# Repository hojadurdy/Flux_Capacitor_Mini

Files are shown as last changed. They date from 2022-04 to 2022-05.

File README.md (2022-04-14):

# Flux Capacitor Mini

LED Numbers

### WHAT IS IT?
A miniature version of Flux Capacitor from the movie trilogy Back to the Future. Measuring at only 48mm x 38mm (1.89in x 1.5in), it can be easily pocketable . It is constructed with high quality 3D printed frame, sandwiched between stacked Gold Plated PCBs. Featuring 24 LEDs, diffused through bare FR4 material, that animate to create the “fluxxing” effect. It’s 100% decorative, it doesn’t actually let you travel through time. But let's not lose hope. Maybe in the future.

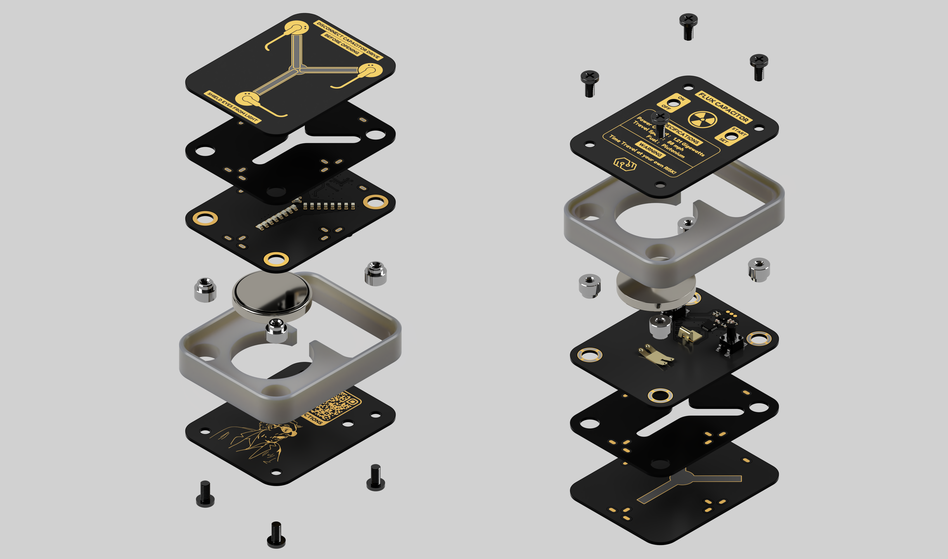
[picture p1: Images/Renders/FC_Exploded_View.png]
LED Numbers


This mini Flux Capacitor is controlled by a Microchip ATtiny816 microcontroller. By using PWM (Pulse Width Modulation) pins for 8 channels of 3 paralleled LEDs, different animation patterns are generated for the fluxxxing effect. In settings mode, users are able change the animation type, speed, and LED brightness. There are 8 animations, 4 animation speeds, 4 LED brightness levels (100%, 75%, 50% and 25%).

### DEVICE SETTINGS
To set your desired animation, speed and LED brightness, you have to start flux condenser in Settings Mode. In order to do that, first you have to turn off your Flux Capacitor (if it's on) by holding "On/Off" button for 3 seconds **(you always have to hold the "On/Off" button for 3 seconds to turn it on or off)**. While holding the “Start/Set” button on the back turn the Flux Capacitor on by holing "On/Off" button for 3 seconds. You can release both buttons when you see all the LEDs start to light up one by one. Now you're in Settings Mode. Some of the LEDs should be on at full brightness and some very dimly lit (so you can see them through FR4 diffuser) according to the configuration it was set. LEDs on each row of all columns, starting from outer to inner are paralleled. LEDs are numbered as shown in the photo below to represent a setting for each LED.

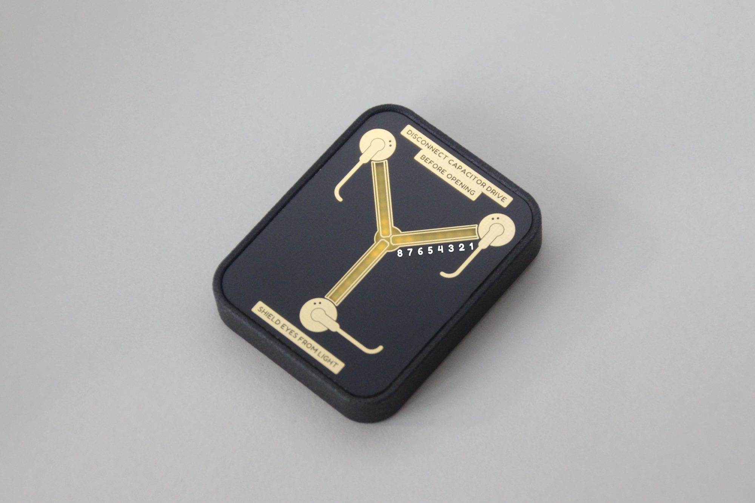
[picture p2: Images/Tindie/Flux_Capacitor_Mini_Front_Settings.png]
Settings


The LEDs display the settings in binary. If it's fully lit then it is shows "on state or in binary 1" and if it's very dimly lit then it is shows "off state or 0 in binary". 
Now the combinations of the LEDs numbered 3, 2, and 1 sets your main animation. If you set those LEDs to different on/off states, you get 8 total combinations and on each set combination LEDs animate in different patterns.
LED number 4 displays setting for flashing animation which animates when you press "Start/Set" button in normal operation. With one LED you get only 2 combination either on or off.
LEDs numbered 5 and 6 displays the setting for animation speed. 2 LEDs make 4 total combinations. For each combination LEDs animate very slow, slow, fast or very fast.
LEDs numbered 7 and 8 displays the setting for LED brightness. For each of the 4 combinations LEDs light up at 25%, 50%, 75% or 100%.
All of the combinations, and setting examğles are shown in the tables below.

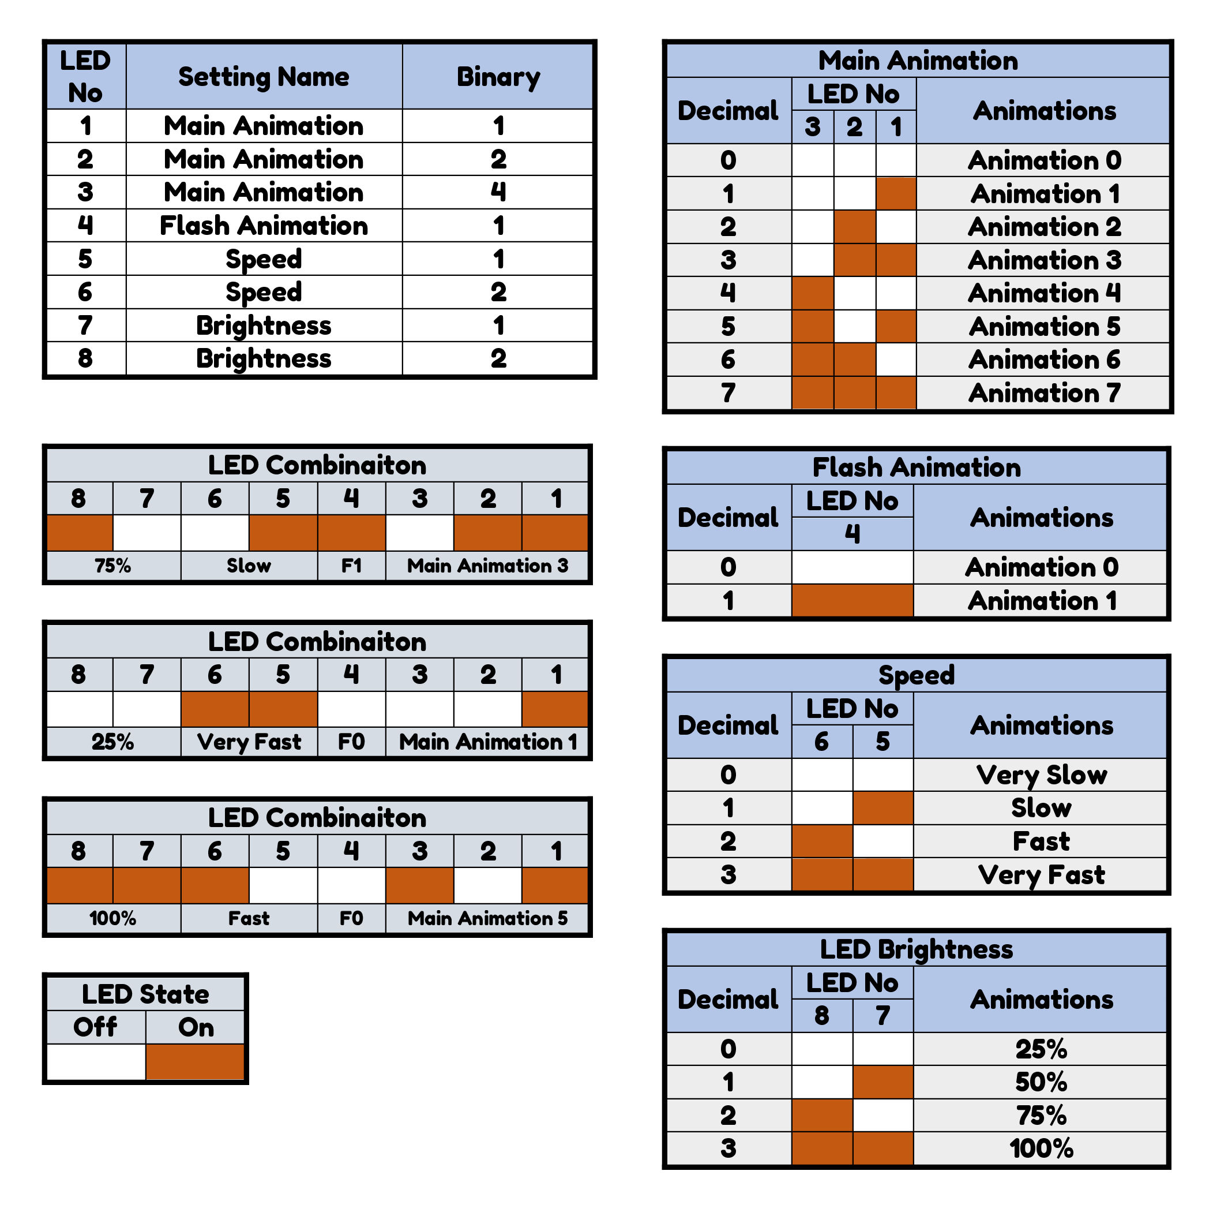
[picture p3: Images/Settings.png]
Settings


You don't have to remember these. There is a QR code on the interior side of back cover PCB. Scan it and it will take you to this page.
To change the LED state, while in Settings Mode, hold the "Start/Set" button. All the LEDs should be turned on very dimly and second after that, starting from LED1 each individual LED gets fully lit. Hold the "Start/Set" button until the fully lit LED reaches the one you want to change. When you change the LED state, if the LED is already set on, it turns off (or dimly lit). If it's at off state (or dimly lit) then it turns on at full brightness. 
If all of this feels complicated to you then I can program the Flux Capacitor with older much simpler version of the firmware by your request. But the older firmware has less functionality. Check it **[HERE](https://www.youtube.com/watch?v=2X2gqoI-mSA)**

You don't have to remember these. There is a QR code on the interior side of back cover PCB. Scan it and it will take you to this page.

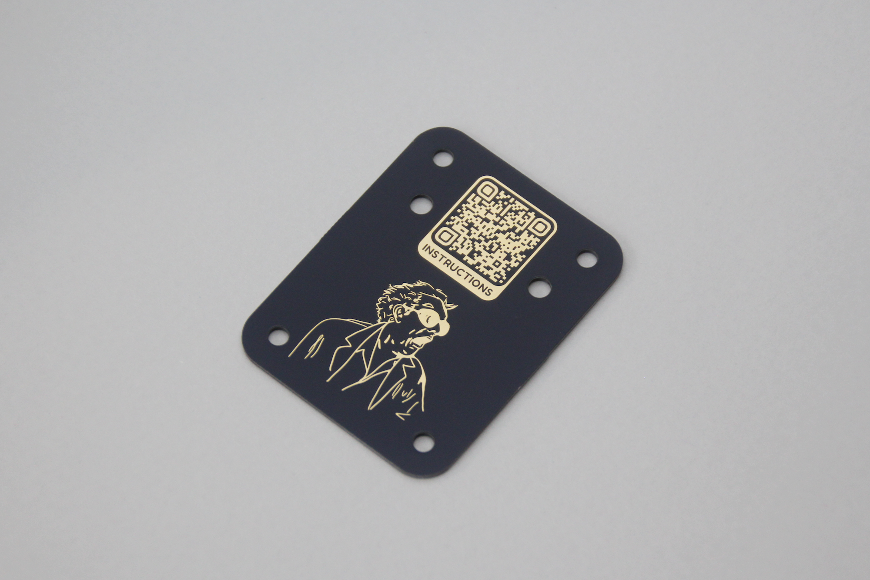
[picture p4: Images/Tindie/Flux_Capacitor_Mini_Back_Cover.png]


Below, all of the LED animations and their LED setting combinations are shown. Also animation patterns might seem different when you run them at different speeds.

https://user-images.githubusercontent.com/43648325/163351795-e4758084-3ac4-411a-833b-632b1832e1c3.mov

https://user-images.githubusercontent.com/43648325/163351857-c6b9a43f-3085-4918-af22-fd343d08b809.mov

https://user-images.githubusercontent.com/43648325/163352711-5db71f97-86e2-47c3-9c65-f71232630f72.mov

https://user-images.githubusercontent.com/43648325/163353298-47ecd2d0-05f4-4908-87b2-38960816e004.mov

### POWER REQUIREMENT
Device requires 1.21 Gigawatts ("Jigowatts") of power to operate. That amount of power is no match for an ordinary power supply. Luckily we've developed a miniature nuclear reactor named LIR2032 that needs to be placed inside the device. LIR2032 also encapsulates a small pellet of Plutonium to be used as fuel to generate enough power. This miniature reactor is able to supply all the power required for the Flux Capacitor. Ok, joke aside this entire paragraph is totally not true.

To really power it, you only need a non-rechargeable CR2032 or rechargeable LIR2032 coin cell battery. Power consumption is drastically lowered. At full brightness, it draws 3.7mA and at 25% brightness it draws 1.8mA of current from the battery. 

CR2032 (Non-Rechargeable) with average of 210mAh battery capacity.

- 100% LED Brightness :  57 Hours
- 25%  LED Brightness :  110 Hours

LIR2032 (Rechargeable) with average of 40mAh battery capacity.

- 100% LED Brightness :  11 Hours
- 25%  LED Brightness :  21 Hours

### WHAT MAKES THIS DEVICE SPECIAL?
First of all, the gold plating on the PCB makes it look luxurious. You can wear it around your neck with an ID card strap, hang it on your keychain or... you can place it on your car's dashboard and try and see if the time travel is possible while you're driving at 88mph. Time travel at your own RISK! If you stuck in unknown territories of time, try turning on the SOS mode of the Flux Capacitor (Animation 5 or 101 LED combination). Help may or may not arrive. NO GUARANTEES. 

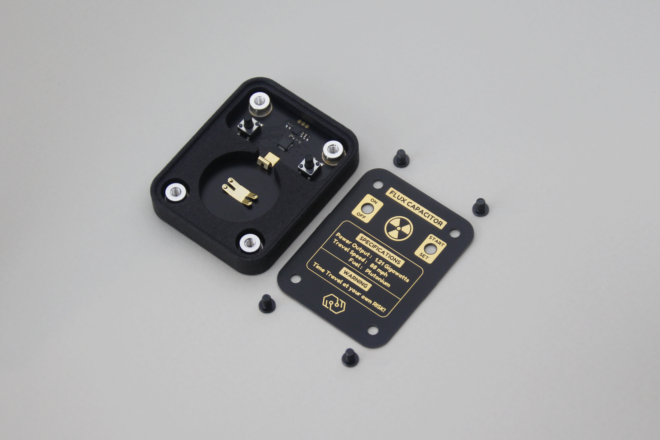
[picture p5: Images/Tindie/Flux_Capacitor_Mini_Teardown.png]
Teardown




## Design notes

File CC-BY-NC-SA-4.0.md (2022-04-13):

# CC-BY-NC-SA-4.0
## Creative Commons Attribution-NonCommercial-ShareAlike 4.0 International

Creative Commons Corporation ("Creative Commons") is not a law firm and
does not provide legal services or legal advice. Distribution of
Creative Commons public licenses does not create a lawyer-client or
other relationship. Creative Commons makes its licenses and related
information available on an "as-is" basis. Creative Commons gives no
warranties regarding its licenses, any material licensed under their
terms and conditions, or any related information. Creative Commons
disclaims all liability for damages resulting from their use to the
fullest extent possible.

Using Creative Commons Public Licenses

Creative Commons public licenses provide a standard set of terms and
conditions that creators and other rights holders may use to share
original works of authorship and other material subject to copyright and
certain other rights specified in the public license below. The
following considerations are for informational purposes only, are not
exhaustive, and do not form part of our licenses.

Considerations for licensors: Our public licenses are intended for use
by those authorized to give the public permission to use material in
ways otherwise restricted by copyright and certain other rights. Our
licenses are irrevocable. Licensors should read and understand the terms
and conditions of the license they choose before applying it. Licensors
should also secure all rights necessary before applying our licenses so
that the public can reuse the material as expected. Licensors should
clearly mark any material not subject to the license. This includes
other CC-licensed material, or material used under an exception or
limitation to copyright. More considerations for licensors :
wiki.creativecommons.org/Considerations\_for\_licensors

Considerations for the public: By using one of our public licenses, a
licensor grants the public permission to use the licensed material under
specified terms and conditions. If the licensor's permission is not
necessary for any reason–for example, because of any applicable
exception or limitation to copyright–then that use is not regulated by
the license. Our licenses grant only permissions under copyright and
certain other rights that a licensor has authority to grant. Use of the
licensed material may still be restricted for other reasons, including
because others have copyright or other rights in the material. A
licensor may make special requests, such as asking that all changes be
marked or described. Although not required by our licenses, you are
encouraged to respect those requests where reasonable. More
considerations for the public :
wiki.creativecommons.org/Considerations\_for\_licensees

Creative Commons Attribution-NonCommercial-ShareAlike 4.0 International
Public License

By exercising the Licensed Rights (defined below), You accept and agree
to be bound by the terms and conditions of this Creative Commons
Attribution-NonCommercial-ShareAlike 4.0 International Public License
("Public License"). To the extent this Public License may be interpreted
as a contract, You are granted the Licensed Rights in consideration of
Your acceptance of these terms and conditions, and the Licensor grants
You such rights in consideration of benefits the Licensor receives from
making the Licensed Material available under these terms and conditions.

Section 1 – Definitions.

-   a. Adapted Material means material subject to Copyright and Similar
    Rights that is derived from or based upon the Licensed Material and
    in which the Licensed Material is translated, altered, arranged,
    transformed, or otherwise modified in a manner requiring permission
    under the Copyright and Similar Rights held by the Licensor. For
    purposes of this Public License, where the Licensed Material is a
    musical work, performance, or sound recording, Adapted Material is
    always produced where the Licensed Material is synched in timed
    relation with a moving image.
-   b. Adapter's License means the license You apply to Your Copyright
    and Similar Rights in Your contributions to Adapted Material in
    accordance with the terms and conditions of this Public License.
-   c. BY-NC-SA Compatible License means a license listed at
    creativecommons.org/compatiblelicenses, approved by Creative Commons
    as essentially the equivalent of this Public License.
-   d. Copyright and Similar Rights means copyright and/or similar
    rights closely related to copyright including, without limitation,
    performance, broadcast, sound recording, and Sui Generis Database
    Rights, without regard to how the rights are labeled or categorized.
    For purposes of this Public License, the rights specified in Section
    2(b)(1)-(2) are not Copyright and Similar Rights.
-   e. Effective Technological Measures means those measures that, in
    the absence of proper authority, may not be circumvented under laws
    fulfilling obligations under Article 11 of the WIPO Copyright Treaty
    adopted on December 20, 1996, and/or similar international
    agreements.
-   f. Exceptions and Limitations means fair use, fair dealing, and/or
    any other exception or limitation to Copyright and Similar Rights
    that applies to Your use of the Licensed Material.
-   g. License Elements means the license attributes listed in the name
    of a Creative Commons Public License. The License Elements of this
    Public License are Attribution, NonCommercial, and ShareAlike.
-   h. Licensed Material means the artistic or literary work, database,
    or other material to which the Licensor applied this Public License.
-   i. Licensed Rights means the rights granted to You subject to the
    terms and conditions of this Public License, which are limited to
    all Copyright and Similar Rights that apply to Your use of the
    Licensed Material and that the Licensor has authority to license.
-   j. Licensor means the individual(s) or entity(ies) granting rights
    under this Public License.
-   k. NonCommercial means not primarily intended for or directed
    towards commercial advantage or monetary compensation. For purposes
    of this Public License, the exchange of the Licensed Material for
    other material subject to Copyright and Similar Rights by digital
    file-sharing or similar means is NonCommercial provided there is no
    payment of monetary compensation in connection with the exchange.
-   l. Share means to provide material to the public by any means or
    process that requires permission under the Licensed Rights, such as
    reproduction, public display, public performance, distribution,
    dissemination, communication, or importation, and to make material
    available to the public including in ways that members of the public
    may access the material from a place and at a time individually
    chosen by them.
-   m. Sui Generis Database Rights means rights other than copyright
    resulting from Directive 96/9/EC of the European Parliament and of
    the Council of 11 March 1996 on the legal protection of databases,
    as amended and/or succeeded, as well as other essentially equivalent
    rights anywhere in the world.
-   n. You means the individual or entity exercising the Licensed Rights
    under this Public License. Your has a corresponding meaning.

Section 2 – Scope.

-   a. License grant.
    -   1. Subject to the terms and conditions of this Public License,
        the Licensor hereby grants You a worldwide, royalty-free,
        non-sublicensable, non-exclusive, irrevocable license to
        exercise the Licensed Rights in the Licensed Material to:
        -   A. reproduce and Share the Licensed Material, in whole or in
            part, for NonCommercial purposes only; and
        -   B. produce, reproduce, and Share Adapted Material for
            NonCommercial purposes only.
    -   2. Exceptions and Limitations. For the avoidance of doubt, where
        Exceptions and Limitations apply to Your use, this Public
        License does not apply, and You do not need to comply with its
        terms and conditions.
    -   3. Term. The term of this Public License is specified in Section
        6(a).
    -   4. Media and formats; technical modifications allowed. The
        Licensor authorizes You to exercise the Licensed Rights in all
        media and formats whether now known or hereafter created, and to
        make technical modifications necessary to do so. The Licensor
        waives and/or agrees not to assert any right or authority to
        forbid You from making technical modifications necessary to
        exercise the Licensed Rights, including technical modifications
        necessary to circumvent Effective Technological Measures. For
        purposes of this Public License, simply making modifications
        authorized by this Section 2(a)(4) never produces Adapted
        Material.
    -   5. Downstream recipients.
        -   A. Offer from the Licensor – Licensed Material. Every
            recipient of the Licensed Material automatically receives an
            offer from the Licensor to exercise the Licensed Rights
            under the terms and conditions of this Public License.
        -   B. Additional offer from the Licensor – Adapted Material.
            Every recipient of Adapted Material from You automatically
            receives an offer from the Licensor to exercise the Licensed
            Rights in the Adapted Material under the conditions of the
            Adapter's License You apply.
        -   C. No downstream restrictions. You may not offer or impose
            any additional or different terms or conditions on, or apply
            any Effective Technological Measures to, the Licensed
            Material if doing so restricts exercise of the Licensed
            Rights by any recipient of the Licensed Material.
    -   6. No endorsement. Nothing in this Public License constitutes or
        may be construed as permission to assert or imply that You are,
        or that Your use of the Licensed Material is, connected with, or
        sponsored, endorsed, or granted official status by, the Licensor
        or others designated to receive attribution as provided in
        Section 3(a)(1)(A)(i).
-   b. Other rights.
    -   1. Moral rights, such as the right of integrity, are not
        licensed under this Public License, nor are publicity, privacy,
        and/or other similar personality rights; however, to the extent
        possible, the Licensor waives and/or agrees not to assert any
        such rights held by the Licensor to the limited extent necessary
        to allow You to exercise the Licensed Rights, but not otherwise.
    -   2. Patent and trademark rights are not licensed under this
        Public License.
    -   3. To the extent possible, the Licensor waives any right to
        collect royalties from You for the exercise of the Licensed
        Rights, whether directly or through a collecting society under
        any voluntary or waivable statutory or compulsory licensing
        scheme. In all other cases the Licensor expressly reserves any
        right to collect such royalties, including when the Licensed
        Material is used other than for NonCommercial purposes.

Section 3 – License Conditions.

Your exercise of the Licensed Rights is expressly made subject to the
following conditions.

-   a. Attribution.
    -   1. If You Share the Licensed Material (including in modified
        form), You must:
        -   A. retain the following if it is supplied by the Licensor
            with the Licensed Material:
            -   i. identification of the creator(s) of the Licensed
                Material and any others designated to receive
                attribution, in any reasonable manner requested by the
                Licensor (including by pseudonym if designated);
            -   ii. a copyright notice;
            -   iii. a notice that refers to this Public License;
            -   iv. a notice that refers to the disclaimer of
                warranties;
            -   v. a URI or hyperlink to the Licensed Material to the
                extent reasonably practicable;

        -   B. indicate if You modified the Licensed Material and retain
            an indication of any previous modifications; and
        -   C. indicate the Licensed Material is licensed under this
            Public License, and include the text of, or the URI or
            hyperlink to, this Public License.
    -   2. You may satisfy the conditions in Section 3(a)(1) in any
        reasonable manner based on the medium, means, and context in
        which You Share the Licensed Material. For example, it may be
        reasonable to satisfy the conditions by providing a URI or
        hyperlink to a resource that includes the required information.
    -   3. If requested by the Licensor, You must remove any of the
        information required by Section 3(a)(1)(A) to the extent
        reasonably practicable.
-   b. ShareAlike.In addition to the conditions in Section 3(a), if You
    Share Adapted Material You produce, the following conditions also
    apply.
    -   1. The Adapter's License You apply must be a Creative Commons
        license with the same License Elements, this version or later,
        or a BY-NC-SA Compatible License.
    -   2. You must include the text of, or the URI or hyperlink to, the
        Adapter's License You apply. You may satisfy this condition in
        any reasonable manner based on the medium, means, and context in
        which You Share Adapted Material.
    -   3. You may not offer or impose any additional or different terms
        or conditions on, or apply any Effective Technological Measures
        to, Adapted Material that restrict exercise of the rights
        granted under the Adapter's License You apply.

Section 4 – Sui Generis Database Rights.

Where the Licensed Rights include Sui Generis Database Rights that apply
to Your use of the Licensed Material:

-   a. for the avoidance of doubt, Section 2(a)(1) grants You the right
    to extract, reuse, reproduce, and Share all or a substantial portion
    of the contents of the database for NonCommercial purposes only;
-   b. if You include all or a substantial portion of the database
    contents in a database in which You have Sui Generis Database
    Rights, then the database in which You have Sui Generis Database
    Rights (but not its individual contents) is Adapted Material,
    including for purposes of Section 3(b); and
-   c. You must comply with the conditions in Section 3(a) if You Share
    all or a substantial portion of the contents of the database.  
    For the avoidance of doubt, this Section 4 supplements and does not
    replace Your obligations under this Public License where the
    Licensed Rights include other Copyright and Similar Rights.

Section 5 – Disclaimer of Warranties and Limitation of Liability.

-   a. Unless otherwise separately undertaken by the Licensor, to the
    extent possible, the Licensor offers the Licensed Material as-is and
    as-available, and makes no representations or warranties of any kind
    concerning the Licensed Material, whether express, implied,
    statutory, or other. This includes, without limitation, warranties
    of title, merchantability, fitness for a particular purpose,
    non-infringement, absence of latent or other defects, accuracy, or
    the presence or absence of errors, whether or not known or
    discoverable. Where disclaimers of warranties are not allowed in
    full or in part, this disclaimer may not apply to You.
-   b. To the extent possible, in no event will the Licensor be liable
    to You on any legal theory (including, without limitation,
    negligence) or otherwise for any direct, special, indirect,
    incidental, consequential, punitive, exemplary, or other losses,
    costs, expenses, or damages arising out of this Public License or
    use of the Licensed Material, even if the Licensor has been advised
    of the possibility of such losses, costs, expenses, or damages.
    Where a limitation of liability is not allowed in full or in part,
    this limitation may not apply to You.
-   c. The disclaimer of warranties and limitation of liability provided
    above shall be interpreted in a manner that, to the extent possible,
    most closely approximates an absolute disclaimer and waiver of all
    liability.

Section 6 – Term and Termination.

-   a. This Public License applies for the term of the Copyright and
    Similar Rights licensed here. However, if You fail to comply with
    this Public License, then Your rights under this Public License
    terminate automatically.
-   b. Where Your right to use the Licensed Material has terminated
    under Section 6(a), it reinstates:

    -   1. automatically as of the date the violation is cured, provided
        it is cured within 30 days of Your discovery of the violation;
        or
    -   2. upon express reinstatement by the Licensor.

    For the avoidance of doubt, this Section 6(b) does not affect any
    right the Licensor may have to seek remedies for Your violations of
    this Public License.

-   c. For the avoidance of doubt, the Licensor may also offer the
    Licensed Material under separate terms or conditions or stop
    distributing the Licensed Material at any time; however, doing so
    will not terminate this Public License.
-   d. Sections 1, 5, 6, 7, and 8 survive termination of this Public
    License.

Section 7 – Other Terms and Conditions.

-   a. The Licensor shall not be bound by any additional or different
    terms or conditions communicated by You unless expressly agreed.
-   b. Any arrangements, understandings, or agreements regarding the
    Licensed Material not stated herein are separate from and
    independent of the terms and conditions of this Public License.

Section 8 – Interpretation.

-   a. For the avoidance of doubt, this Public License does not, and
    shall not be interpreted to, reduce, limit, restrict, or impose
    conditions on any use of the Licensed Material that could lawfully
    be made without permission under this Public License.
-   b. To the extent possible, if any provision of this Public License
    is deemed unenforceable, it shall be automatically reformed to the
    minimum extent necessary to make it enforceable. If the provision
    cannot be reformed, it shall be severed from this Public License
    without affecting the enforceability of the remaining terms and
    conditions.
-   c. No term or condition of this Public License will be waived and no
    failure to comply consented to unless expressly agreed to by the
    Licensor.
-   d. Nothing in this Public License constitutes or may be interpreted
    as a limitation upon, or waiver of, any privileges and immunities
    that apply to the Licensor or You, including from the legal
    processes of any jurisdiction or authority.

Creative Commons is not a party to its public licenses. Notwithstanding,
Creative Commons may elect to apply one of its public licenses to
material it publishes and in those instances will be considered the
"Licensor." The text of the Creative Commons public licenses is
dedicated to the public domain under the CC0 Public Domain Dedication.
Except for the limited purpose of indicating that material is shared
under a Creative Commons public license or as otherwise permitted by the
Creative Commons policies published at creativecommons.org/policies,
Creative Commons does not authorize the use of the trademark "Creative
Commons" or any other trademark or logo of Creative Commons without its
prior written consent including, without limitation, in connection with
any unauthorized modifications to any of its public licenses or any
other arrangements, understandings, or agreements concerning use of
licensed material. For the avoidance of doubt, this paragraph does not
form part of the public licenses.

Creative Commons may be contacted at creativecommons.org.

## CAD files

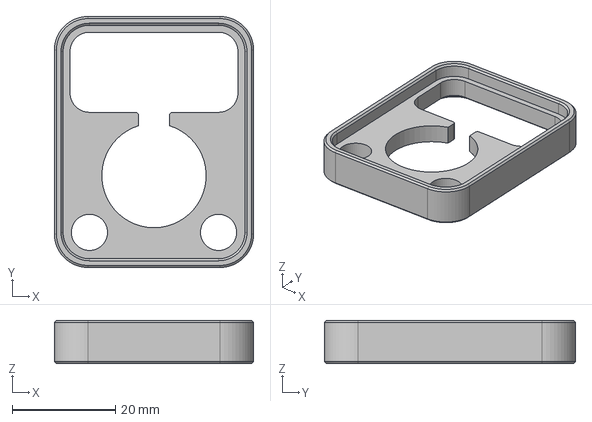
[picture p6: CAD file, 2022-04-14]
3D/Case/FCM_Case_FDM.step
38.6 x 48.6 x 8.40 mm

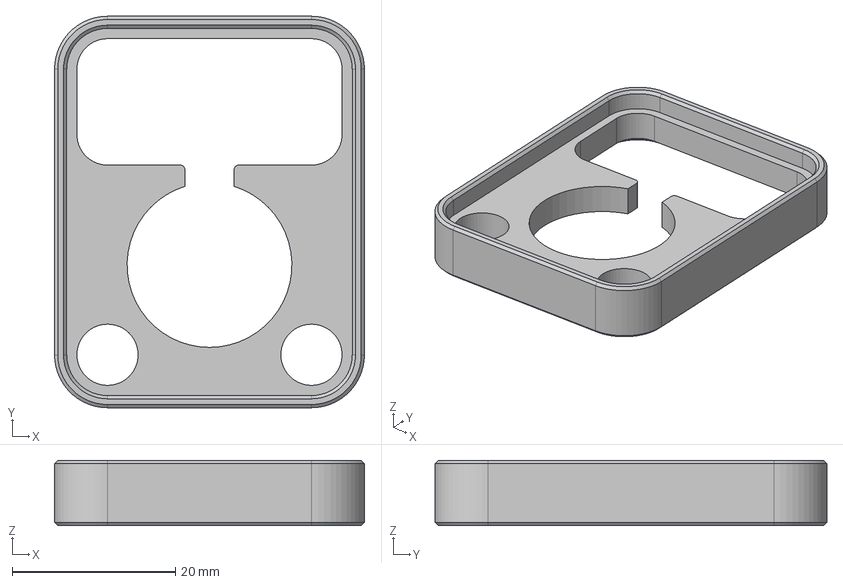
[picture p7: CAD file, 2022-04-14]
3D/Case/FCM_Case_V2.step
38.0 x 48.0 x 8.00 mm

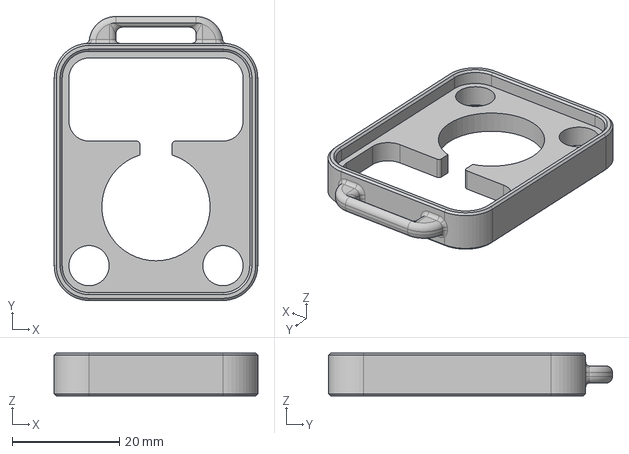
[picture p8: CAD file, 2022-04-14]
3D/Case/FCM_Case_Keychain_V3.step
38.0 x 53.0 x 8.00 mm

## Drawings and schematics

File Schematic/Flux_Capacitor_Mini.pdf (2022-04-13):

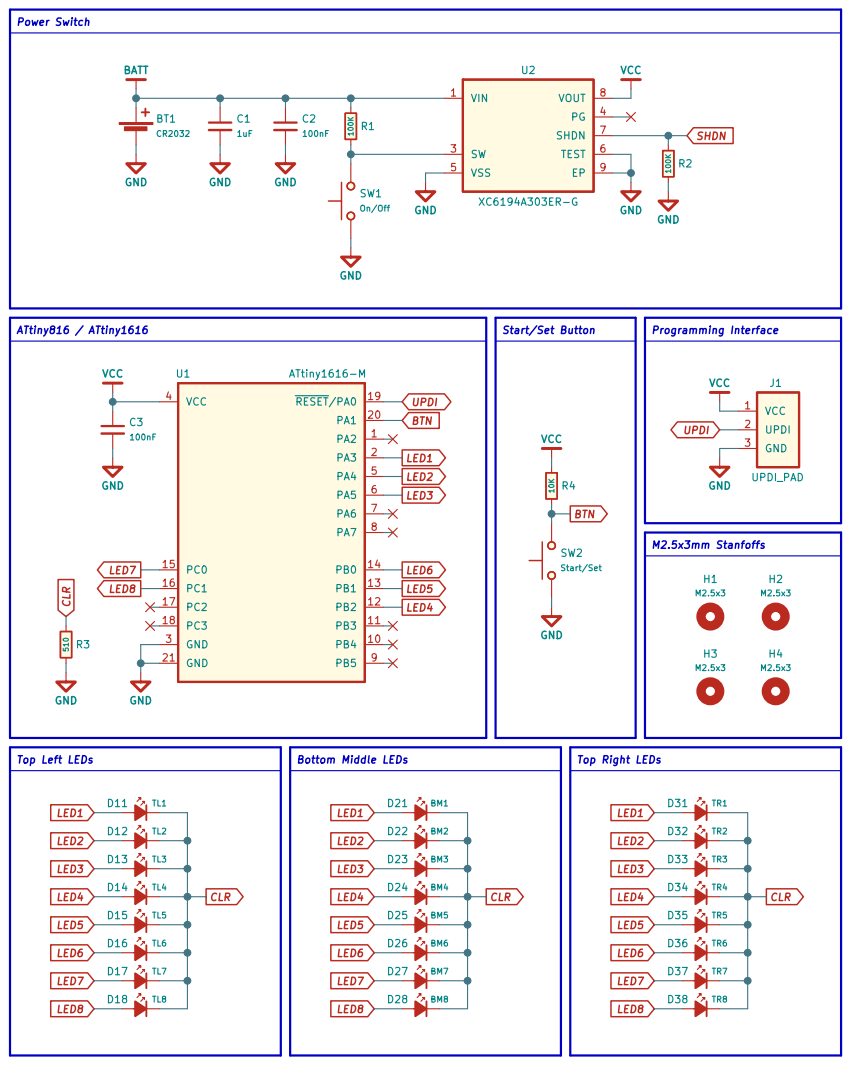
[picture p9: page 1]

Curious Design Labs | Hojadurdy Durdygylyjov

Small PCB version of Flux Capacitor from the movie Back to the Future

License: CC BY-NC-SA 4.0 Sheet: 1/1

File: Flux_Capacitor_Mini.kicad_sch

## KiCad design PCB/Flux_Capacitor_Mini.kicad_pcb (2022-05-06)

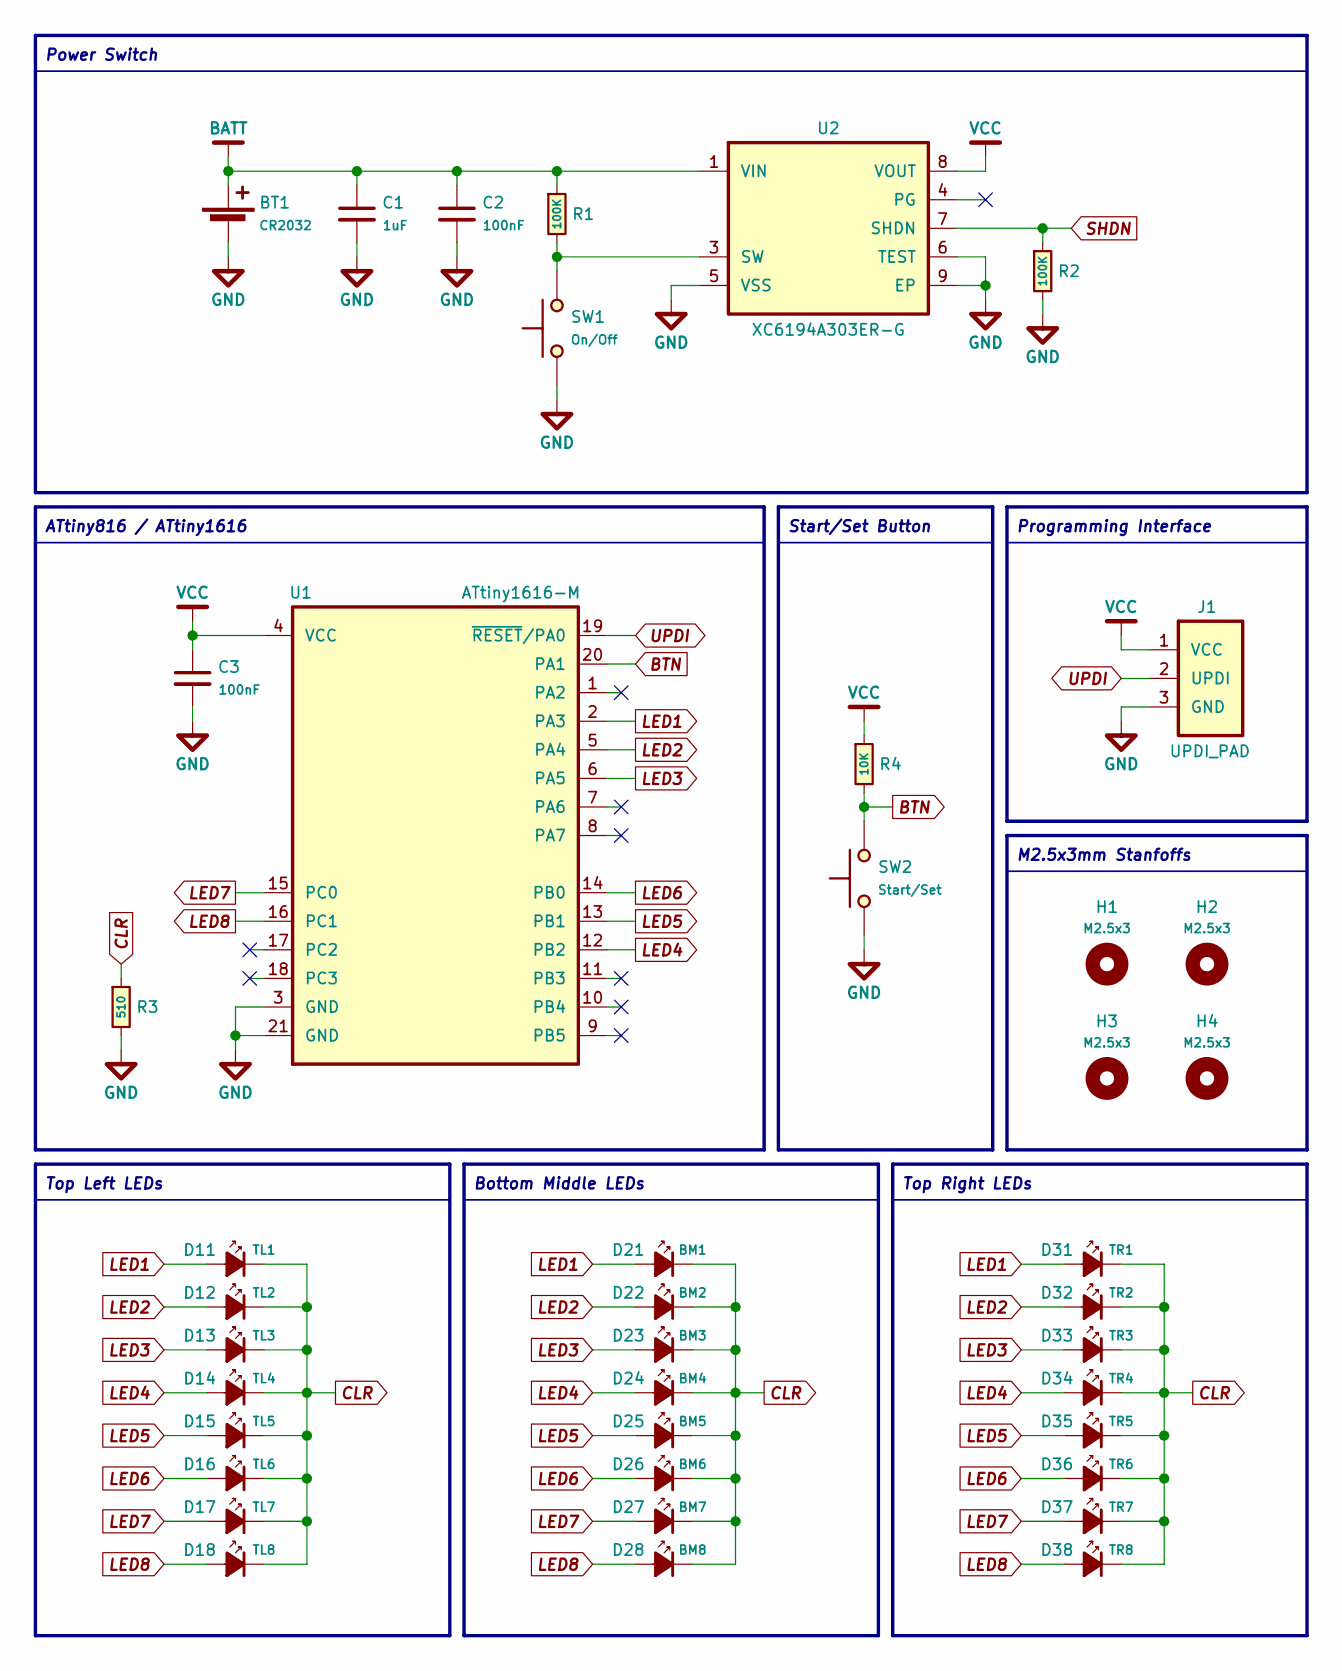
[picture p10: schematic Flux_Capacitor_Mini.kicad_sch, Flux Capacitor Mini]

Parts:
BT1: CR2032; CR2032_MY-FJ-113LM_MY-ZJ-110
C1: 1uF; C_0402_1005Metric
C2, C3: 100nF; C_0402_1005Metric
D11: TL1; LED_0603_1608Metric
D12: TL2; LED_0603_1608Metric
D13: TL3; LED_0603_1608Metric
D14: TL4; LED_0603_1608Metric
D15: TL5; LED_0603_1608Metric
D16: TL6; LED_0603_1608Metric
D17: TL7; LED_0603_1608Metric
D18: TL8; LED_0603_1608Metric
D21: BM1; LED_0603_1608Metric
D22: BM2; LED_0603_1608Metric
D23: BM3; LED_0603_1608Metric
D24: BM4; LED_0603_1608Metric
D25: BM5; LED_0603_1608Metric
D26: BM6; LED_0603_1608Metric
D27: BM7; LED_0603_1608Metric
D28: BM8; LED_0603_1608Metric
D31: TR1; LED_0603_1608Metric
D32: TR2; LED_0603_1608Metric
D33: TR3; LED_0603_1608Metric
D34: TR4; LED_0603_1608Metric
D35: TR5; LED_0603_1608Metric
D36: TR6; LED_0603_1608Metric
D37: TR7; LED_0603_1608Metric
D38: TR8; LED_0603_1608Metric
H1, H2, H3, H4: M2.5x3; SMTSO2530CTJ
J1: UPDI_PAD; PogoPad_1x03_P1.27mm
R1, R2: 100K; R_0402_1005Metric
R3: 510; R_0402_1005Metric
R4: 10K; R_0402_1005Metric
SW1: On/Off; SW_SPST_4.5x4.5mm
SW2: Start/Set; SW_SPST_4.5x4.5mm
U1: ATtiny1616-M; VQFN-20-1EP_3x3mm_P0.4mm_EP1.7x1.7mm
U2: XC6194A303ER-G; USP-8B06_2.0x2.0mm_P0.5mm_EP1.0x1.8mm

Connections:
BATT: BT1.1 (+), C1.1, C2.1, R1.1, U2.1 (VIN)
BTN: R4.2, SW2.2, U1.20 (PA1)
CLR: D11.1 (K), D12.1 (K), D13.1 (K), D14.1 (K), D15.1 (K), D16.1 (K), D17.1 (K), D18.1 (K), D21.1 (K), D22.1 (K), D23.1 (K), D24.1 (K), D25.1 (K), D26.1 (K), D27.1 (K), D28.1 (K), D31.1 (K), D32.1 (K), D33.1 (K), D34.1 (K), D35.1 (K), D36.1 (K), D37.1 (K), D38.1 (K), R3.1
GND: BT1.2 (-), C1.2, C2.2, C3.2, J1.3 (GND), R2.2, R3.2, SW1.1, SW2.1, U1.3 (GND), U1.21 (GND), U2.5 (VSS), U2.6 (TEST), U2.9 (EP)
LED1: D11.2 (A), D21.2 (A), D31.2 (A), U1.2 (PA3)
LED2: D12.2 (A), D22.2 (A), D32.2 (A), U1.5 (PA4)
LED3: D13.2 (A), D23.2 (A), D33.2 (A), U1.6 (PA5)
LED4: D14.2 (A), D24.2 (A), D34.2 (A), U1.12 (PB2)
LED5: D15.2 (A), D25.2 (A), D35.2 (A), U1.13 (PB1)
LED6: D16.2 (A), D26.2 (A), D36.2 (A), U1.14 (PB0)
LED7: D17.2 (A), D27.2 (A), D37.2 (A), U1.15 (PC0)
LED8: D18.2 (A), D28.2 (A), D38.2 (A), U1.16 (PC1)
unnamed: R1.2, SW1.2, U2.3 (SW)
SHDN: R2.1, U2.7 (SHDN)
UPDI: J1.2 (UPDI), U1.19 (~RESET/PA0)
VCC: C3.1, J1.1 (VCC), R4.1, U1.4 (VCC), U2.8 (VOUT)

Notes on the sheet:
ATtiny816 / ATtiny1616
Bottom Middle LEDs
Start/Set Button
Top Right LEDs
M2.5x3mm Stanfoffs
Programming Interface
Top Left LEDs
Power Switch

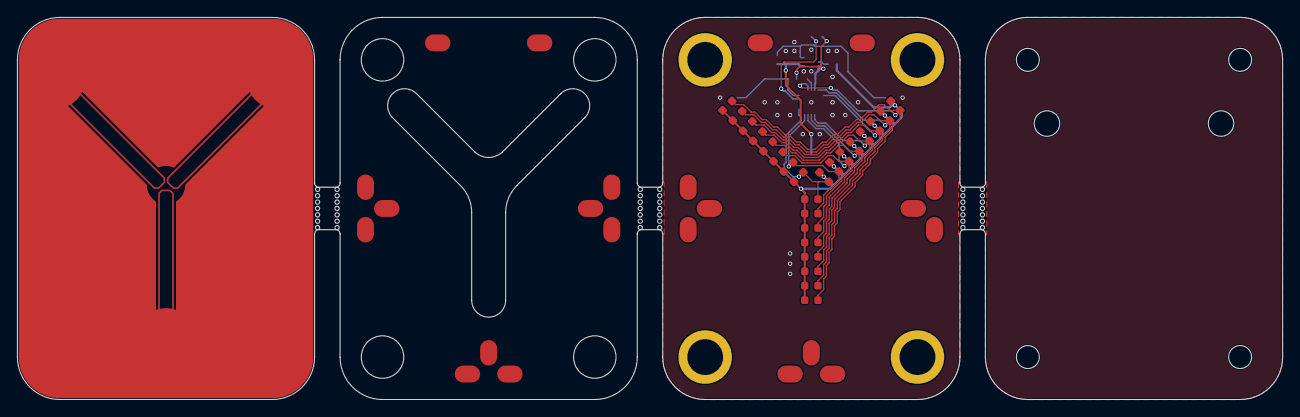
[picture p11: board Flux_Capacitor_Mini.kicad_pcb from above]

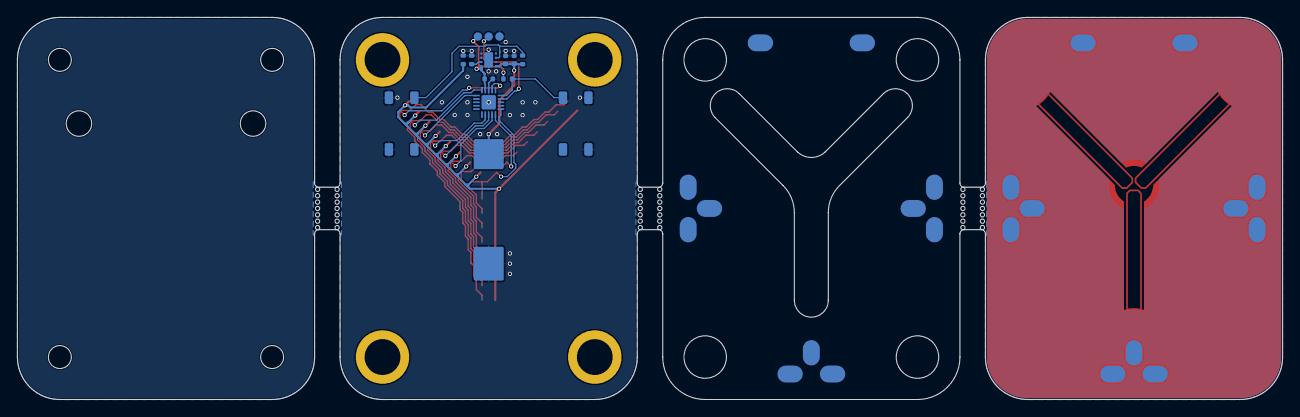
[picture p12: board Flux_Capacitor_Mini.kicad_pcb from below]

Board: 2 copper layers, 149.0 x 45.0 mm, 53 parts (29 on the bottom side), 16 nets.

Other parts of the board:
kibuzzard-62311D83, kibuzzard-62311D83#2: G***; kibuzzard-62311D83
kibuzzard-62327BD2: G***; kibuzzard-62327BD2
kibuzzard-62327D38: G***; kibuzzard-62327D38
kibuzzard-62330E41: G***; kibuzzard-62330E41
kibuzzard-623256DE: G***; kibuzzard-623256DE
kibuzzard-623278F0: G***; kibuzzard-623278F0
kibuzzard-6232791A: G***; kibuzzard-6232791A
kibuzzard-62327207: G***; kibuzzard-62327207
kibuzzard-62327418: G***; kibuzzard-62327418
kibuzzard-62327445: G***; kibuzzard-62327445
kibuzzard-62327907: G***; kibuzzard-62327907

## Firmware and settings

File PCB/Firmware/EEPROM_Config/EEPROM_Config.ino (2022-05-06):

#include <EEPROM.h>

//------ PIN DEFINITIONS ------//

#define led1    16
#define led2    0
#define led3    1
#define led4    7
#define led5    8
#define led6    9
#define led7    10
#define led8    11
#define button  14

//-- BUTTON HOLD TIME PRESETS --//

//Counter Value
float pressLength_ms = 0;

//Main Animation Sequence - 3bit
#define main_animation1     1000     //LSB   1 Second
#define main_animation2     2000     //      2 Seconds
#define main_animation4     3000     //MSB   3 Seconds

//Flash Animation Sequence - 1bit
#define flash_animation1    4000     //      4 Seconds

//Animation Speed - 2bit
#define speed1              5000     //LSB   5 Seconds
#define speed2              6000     //MSB   6 Seconds

//LED Brightness - 2bit
#define brightness1         7000     //LSB   7 Seconds
#define brightness2         8000     //MSB   8 Seconds

//-- SETTINGS EEPROM ADDRESS --//

#define main_animation1_addr    11
#define main_animation2_addr    12
#define main_animation4_addr    13
#define flash_animation1_addr   14
#define speed1_addr             15
#define speed2_addr             16
#define brightness1_addr        17
#define brightness2_addr        18

byte main_animation1_val;
byte main_animation2_val;
byte main_animation4_val;
byte flash_animation1_val;
byte speed1_val;
byte speed2_val;
byte brightness1_val;
byte brightness2_val;

//-----------------------------//

int buttonState = 1;      //Button state while not being pressed. When pressed pulls pin to GND.

byte startup;
byte startUpState;
byte startUpMode;
byte main_animationSequence;
byte flash_animationSequence;
byte animationSpeed;
byte ledBrightness;

void setup() {               
    pinMode(led1, OUTPUT); 
    pinMode(led2, OUTPUT);
    pinMode(led3, OUTPUT);
    pinMode(led4, OUTPUT);
    pinMode(led5, OUTPUT);
    pinMode(led6, OUTPUT);
    pinMode(led7, OUTPUT);
    pinMode(led8, OUTPUT); 
    pinMode(button, INPUT);   

    EEPROM.write(1, 1);
    EEPROM.write(11, 0);
    EEPROM.write(12, 0);
    EEPROM.write(13, 0);
    EEPROM.write(14, 0);
    EEPROM.write(15, 0);
    EEPROM.write(16, 1);
    EEPROM.write(17, 0);
    EEPROM.write(18, 0);
}

void loop() {
    startUpSequence();
    
    analogWrite(led1, ledBrightness);
    delay(animationSpeed*2);
    checkButton();
    analogWrite(led2, ledBrightness);
    delay(animationSpeed*2);
    checkButton();
    analogWrite(led3, ledBrightness);
    delay(animationSpeed*2);
    checkButton();
    analogWrite(led4, ledBrightness);
    delay(animationSpeed*2);
    checkButton();
    analogWrite(led5, ledBrightness);
    delay(animationSpeed*2);
    checkButton();
    analogWrite(led6, ledBrightness);
    delay(animationSpeed*2);
    checkButton();
    analogWrite(led7, ledBrightness);
    delay(animationSpeed*2);
    checkButton();
    analogWrite(led8, ledBrightness);
    delay(animationSpeed*2);
    checkButton();
}

void startUpSequence() {
    startUpMode = EEPROM.read(1);
    main_animation1_val = EEPROM.read(main_animation1_addr);
    main_animation2_val = EEPROM.read(main_animation2_addr);
    main_animation4_val = EEPROM.read(main_animation4_addr);
    flash_animation1_val = EEPROM.read(flash_animation1_addr);
    speed1_val = EEPROM.read(speed1_addr);
    speed2_val = EEPROM.read(speed2_addr);
    brightness1_val = EEPROM.read(brightness1_addr);
    brightness2_val = EEPROM.read(brightness2_addr);

    if(startUpMode == 0 && digitalRead(button) == 0 && startup == 1) {
        analogWrite(led1, 200);
        delay(150);
        analogWrite(led2, 200);
        delay(150);
        analogWrite(led3, 200);
        delay(150);
        analogWrite(led4, 200);
        delay(150);
        analogWrite(led5, 200);
        delay(150);
        analogWrite(led6, 200);
        delay(150);
        analogWrite(led7, 200);
        delay(150);
        analogWrite(led8, 200);
        delay(150);

        startup = 0;
    }
    else {
      //Do Nothing
    }

    //Determine Main Animation Sequence According to Values from 3 EEPROM Addresses
    if(main_animation4_val == 0 && main_animation2_val == 0 && main_animation1_val == 0) {
        main_animationSequence = 1;
    }
    else if(main_animation4_val == 0 && main_animation2_val == 0 && main_animation1_val == 1) {
        main_animationSequence = 2;
    }
    else if(main_animation4_val == 0 && main_animation2_val == 1 && main_animation1_val == 0) {
        main_animationSequence = 3;
    }
    else if(main_animation4_val == 0 && main_animation2_val == 1 && main_animation1_val == 1) {
        main_animationSequence = 4;
    }
    else if(main_animation4_val == 1 && main_animation2_val == 0 && main_animation1_val == 0) {
        main_animationSequence = 5;
    }
    else if(main_animation4_val == 1 && main_animation2_val == 0 && main_animation1_val == 1) {
        main_animationSequence = 6;
    }
    else if(main_animation4_val == 1 && main_animation2_val == 1 && main_animation1_val == 0) {
        main_animationSequence = 7;
    }
    else if(main_animation4_val == 1 && main_animation2_val == 1 && main_animation1_val == 1) {
        main_animationSequence = 8;
    }

    //Determine Flash Animation Sequence According to Value from EEPROM Address
    if(flash_animation1_val == 0) {
        flash_animationSequence = 1;
    }
    else if(flash_animation1_val == 1) {
        flash_animationSequence = 2;
    }

    //Determine Animation Speed According to Values from 2 EEPROM Addresses
    if(speed2_val == 0 && speed1_val == 0) {
        animationSpeed = 100;
    }
    else if(speed2_val == 0 && speed1_val == 1) {
        animationSpeed = 75;
    }
    else if(speed2_val == 1 && speed1_val == 0) {
        animationSpeed = 50;
    }
    else if(speed2_val == 1 && speed1_val == 1) {
        animationSpeed = 25;
    }

    //Determine LED Brightness According to Values from 2 EEPROM Addresses
    if(brightness2_val == 0 && brightness1_val == 0) {
        ledBrightness = 63;
    }
    else if(brightness2_val == 0 && brightness1_val == 1) {
        ledBrightness = 127;
    }
    else if(brightness2_val == 1 && brightness1_val == 0) {
        ledBrightness = 191;
    }
    else if(brightness2_val == 1 && brightness1_val == 1) {
        ledBrightness = 255;
    }
}

void checkButton(){
    while (digitalRead(button) == LOW ){ 
        analogWrite(led1, ledBrightness);
        analogWrite(led2, 0);
        analogWrite(led3, ledBrightness);
        analogWrite(led4, 0);
        analogWrite(led5, ledBrightness);
        analogWrite(led6, 0);
        analogWrite(led7, ledBrightness);
        analogWrite(led8, 0);
    }
}

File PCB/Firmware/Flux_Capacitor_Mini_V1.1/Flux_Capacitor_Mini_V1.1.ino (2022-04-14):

/************************************************************************************************
 * Ver:     1.1
 * MCU:     ATtiny816-M / ATtiny1616-M
 * Clock:   1MHz Internal
 * Timer:   Enabled (default timer)
 * Startup: 8ms
 * BOD VL:  1.8V
 * EEPROM:  EEPROM Retained
 * 
 * Built in Arduino using Spence Konde's megaTinyCore (https://github.com/SpenceKonde/megaTinyCore)
 * 
 * Copyright 2022, Hojadurdy Durdygylyjov - Curious Design Labs
 * 
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
 * THE SOFTWARE IS PROVIDED "AS IS", WITHOUT WARRANTY OF ANY KIND, EXPRESS OR IMPLIED, INCLUDING 
 * BUT NOT LIMITED TO THE WARRANTIES OF MERCHANTABILITY, FITNESS FOR A PARTICULAR PURPOSE AND 
 * NONINFRINGEMENT. IN NO EVENT SHALL THE AUTHORS OR COPYRIGHT HOLDERS BE LIABLE FOR ANY CLAIM, 
 * DAMAGES OR OTHER LIABILITY, WHETHER IN AN ACTION OF CONTRACT, TORT OR OTHERWISE, ARISING FROM, 
 * OUT OF OR IN CONNECTION WITH THE SOFTWARE OR THE USE OR OTHER DEALINGS IN THE SOFTWARE.
 ************************************************************************************************/

#include <EEPROM.h>

//Pin Definitions

#define button  14
const byte leds[8]={16, 0, 1, 7, 8, 9, 10, 11};

//-- BUTTON HOLD TIME PRESETS --//

//Counter Value
uint16_t pressLength_ms = 0;

//Main Animation Sequence - 3bit
#define main_animation1     1000     //LSB   1 Second
#define main_animation2     2000     //      2 Seconds
#define main_animation4     3000     //MSB   3 Seconds

//Flash Animation Sequence - 1bit
#define flash_animation1    4000     //      4 Seconds

//Animation Speed - 2bit
#define speed1              5000     //LSB   5 Seconds
#define speed2              6000     //MSB   6 Seconds

//LED Brightness - 2bit
#define brightness1         7000     //LSB   7 Seconds
#define brightness2         8000     //MSB   8 Seconds

//-- SETTINGS EEPROM ADDRESS --//

#define main_animation1_addr    11
#define main_animation2_addr    12
#define main_animation4_addr    13
#define flash_animation1_addr   14
#define speed1_addr             15
#define speed2_addr             16
#define brightness1_addr        17
#define brightness2_addr        18

byte main_animation1_val;
byte main_animation2_val;
byte main_animation4_val;
byte flash_animation1_val;
byte speed1_val;
byte speed2_val;
byte brightness1_val;
byte brightness2_val;
float brightnessScaleVal;

//-----------------------------//

int buttonState = 1;      //Button state while not being pressed. When pressed pulls pin to GND.

byte startup;
byte startUpState;
byte startUpMode;
byte main_animationSequence;
byte flash_animationSequence;
byte animationSpeed;
byte ledBrightness;

void setup() {     

    for(int i=0;i<=7;i++) {
        pinMode(leds[i], OUTPUT); 
    }
    pinMode(button, INPUT); 
    
    startUpState = digitalRead(button);
    startUpMode = EEPROM.read(1);
    // If button and EEPROM values are same, do nothing.
    if(startUpState == 1 && startUpMode == 1) {
        //Do Nothing
    }
    else if(startUpState == 0 && startUpMode == 0) {
        //Do Nothing
    }
    // If button and EEPROM values are different, then save the new value
    else if(startUpState == 0 && startUpMode == 1) {
        EEPROM.write(1, startUpState);
    }
    else if(startUpState == 1 && startUpMode == 0) {
        EEPROM.write(1, startUpState);
    } 

    startup = 1;
}

void loop() {
  
    startUpSequence();          
    switch(startUpMode) {
        case 0:
            deviceSettings();
        break;

        case 1:
            deviceRun();
        break;
    }
}

void startUpSequence() {
  
    startUpMode = EEPROM.read(1);
    main_animation1_val = EEPROM.read(main_animation1_addr);
    main_animation2_val = EEPROM.read(main_animation2_addr);
    main_animation4_val = EEPROM.read(main_animation4_addr);
    flash_animation1_val = EEPROM.read(flash_animation1_addr);
    speed1_val = EEPROM.read(speed1_addr);
    speed2_val = EEPROM.read(speed2_addr);
    brightness1_val = EEPROM.read(brightness1_addr);
    brightness2_val = EEPROM.read(brightness2_addr);

    if(startUpMode == 0 && digitalRead(button) == 0 && startup == 1) {
        for(int i=0;i<=7;i++) {
            digitalWrite(leds[i], 1);
            delay(150);
        }
        startup = 0;
    }
    else {
      //Do Nothing
    }

    //Determine Main Animation Sequence According to Values from 3 EEPROM Addresses
    if(main_animation4_val == 0 && main_animation2_val == 0 && main_animation1_val == 0) {
        main_animationSequence = 0;
    }
    else if(main_animation4_val == 0 && main_animation2_val == 0 && main_animation1_val == 1) {
        main_animationSequence = 1;
    }
    else if(main_animation4_val == 0 && main_animation2_val == 1 && main_animation1_val == 0) {
        main_animationSequence = 2;
    }
    else if(main_animation4_val == 0 && main_animation2_val == 1 && main_animation1_val == 1) {
        main_animationSequence = 3;
    }
    else if(main_animation4_val == 1 && main_animation2_val == 0 && main_animation1_val == 0) {
        main_animationSequence = 4;
    }
    else if(main_animation4_val == 1 && main_animation2_val == 0 && main_animation1_val == 1) {
        main_animationSequence = 5;
    }
    else if(main_animation4_val == 1 && main_animation2_val == 1 && main_animation1_val == 0) {
        main_animationSequence = 6;
    }
    else if(main_animation4_val == 1 && main_animation2_val == 1 && main_animation1_val == 1) {
        main_animationSequence = 7;
    }

    //Determine Flash Animation Sequence According to Value from EEPROM Address
    if(flash_animation1_val == 0) {
        flash_animationSequence = 0;
    }
    else if(flash_animation1_val == 1) {
        flash_animationSequence = 1;
    }

    //Determine Animation Speed According to Values from 2 EEPROM Addresses
    if(speed2_val == 0 && speed1_val == 0) {
        animationSpeed = 100;
    }
    else if(speed2_val == 0 && speed1_val == 1) {
        animationSpeed = 75;
    }
    else if(speed2_val == 1 && speed1_val == 0) {
        animationSpeed = 50;
    }
    else if(speed2_val == 1 && speed1_val == 1) {
        animationSpeed = 25;
    }

    //Determine LED Brightness According to Values from 2 EEPROM Addresses
    if(brightness2_val == 0 && brightness1_val == 0) {
        ledBrightness = 63;
    }
    else if(brightness2_val == 0 && brightness1_val == 1) {
        ledBrightness = 127;
    }
    else if(brightness2_val == 1 && brightness1_val == 0) {
        ledBrightness = 191;
    }
    else if(brightness2_val == 1 && brightness1_val == 1) {
        ledBrightness = 255;
    }
}

void deviceSettings() {
  
    showSettings();
    buttonHoldTimer();
    saveSettings();
}
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
